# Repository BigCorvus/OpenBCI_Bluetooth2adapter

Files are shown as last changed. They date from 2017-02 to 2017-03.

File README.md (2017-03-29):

# OpenBCI_Bluetooth2adapter

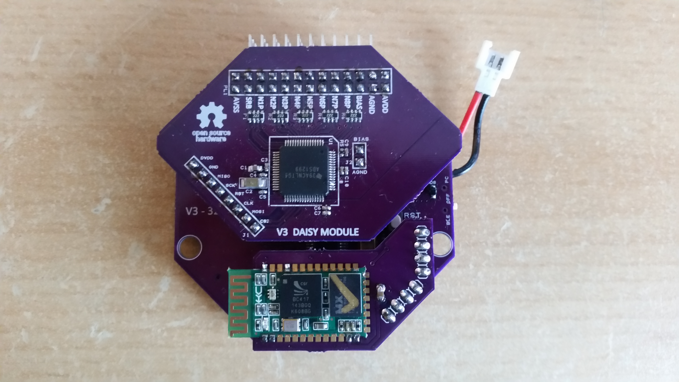
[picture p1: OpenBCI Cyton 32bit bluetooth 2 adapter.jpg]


Eagle files for an adapter board for the OpenBCI 32bit V3 board (Cyton) that enables higher data/sampling rates and eliminates the need for a USB dongle. Reliable operation is possible with 500Hz and 8 channels or 250Hz and 16 Channels. The OpenBCI GUI 2.0 is able to keep up with that.
The bluetooth module used is the common HC-05. Programming the board is still accomplished via dongle/RFduino.

In order for this board to work you have to implement WinslowStrong's changes in firmware (https://github.com/WinslowStrong/OpenBCI_Wired_USB) and you have to set up a baud rate of 230400baud on your bluetooth module (this is the highest rate I've been able to acheive reliably with the HC05). 
I've modified my Cyton board by putting the RFduino module on headers so that it can be removed after flashing the modified firmware. 

A solder jumper is included on the bottom side of the board to enter programming mode. You can short it temporarily using some metal object. In command mode (the LED is blinking slowly) you have to set a baud rate of 38400baud 8N1 and send after each command \r\n. If you enter AT the module should respond with OK.
To set the baud rate just enter AT+UART=230400,0,0 and to set the name type in AT+NAME=OpenBCI32 or whatever name you like. 

Edit: I also created a version for the RN42 module (http://www.digikey.com/product-detail/en/microchip-technology/RN42-I-RM630/RN42-I-RM630-ND/6009311) which can acheive speeds at up to 460800 baud in the system.

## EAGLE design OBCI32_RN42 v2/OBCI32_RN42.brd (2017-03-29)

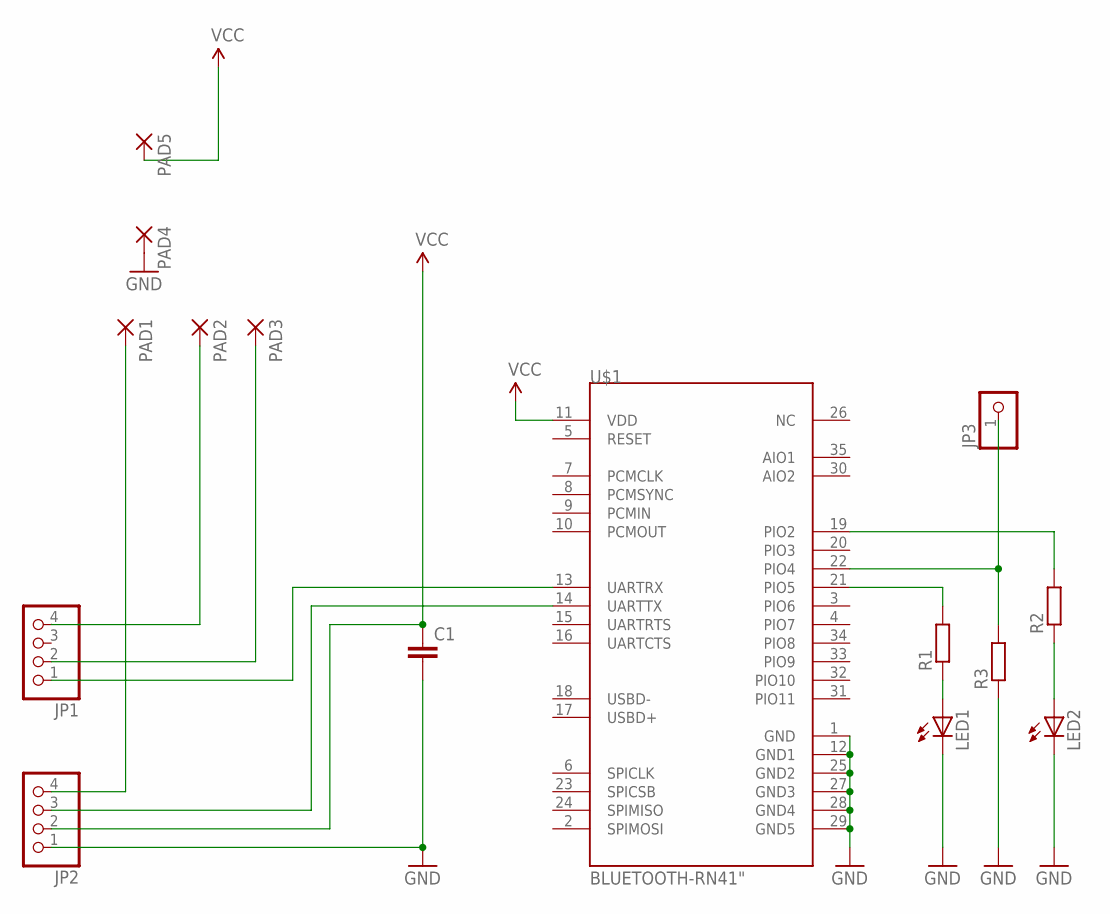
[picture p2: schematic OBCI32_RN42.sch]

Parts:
C1: C-EUC0805; C0805
JP1, JP2: PINHD-1X4; 1X04
JP3: PINHD-1X1; 1X01
LED1, LED2: LEDCHIP-LED0805; CHIP-LED0805
PAD1, PAD2, PAD3, PAD4, PAD5: SMD2; SMD1,27-2,54
R1, R2, R3: R-EU_R0603; R0603
U$1: BLUETOOTH-RN41"; RN41

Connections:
GND: C1.2, JP2.1, LED1.C, LED2.C, PAD4.1, R3.1, U$1.1 (GND), U$1.12 (GND1), U$1.25 (GND2), U$1.27 (GND3), U$1.28 (GND4), U$1.29 (GND5)
unnamed: R1.2, U$1.21 (PIO5)
unnamed: R2.2, U$1.19 (PIO2)
unnamed: JP2.3, U$1.14 (UARTTX)
unnamed: JP1.1, U$1.13 (UARTRX)
unnamed: LED1.A, R1.1
unnamed: JP1.2, PAD3.1
unnamed: JP1.4, PAD2.1
unnamed: JP2.4, PAD1.1
unnamed: LED2.A, R2.1
unnamed: JP3.1, R3.2, U$1.22 (PIO4)
VCC: C1.1, JP2.2, PAD5.1, U$1.11 (VDD)

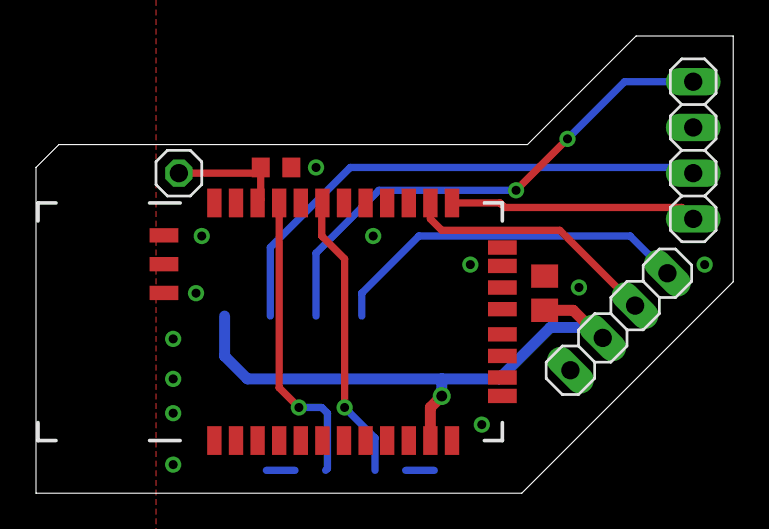
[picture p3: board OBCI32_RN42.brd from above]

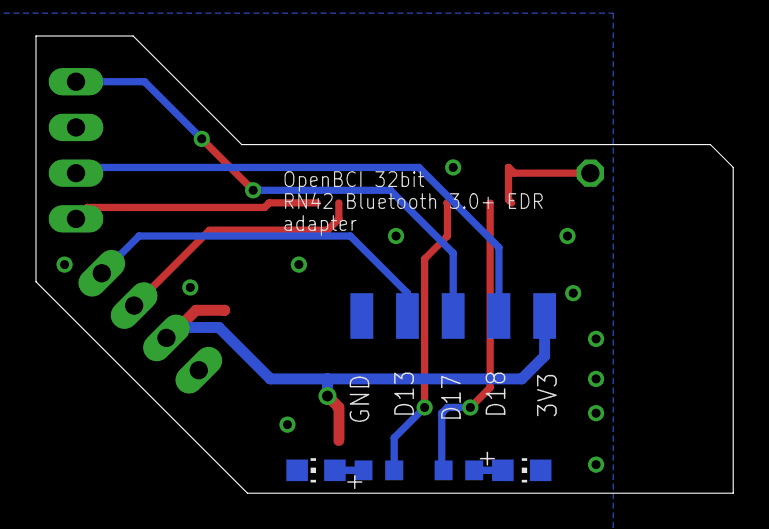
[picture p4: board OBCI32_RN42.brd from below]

Board: 2 copper layers, 38.7 x 25.4 mm, 15 parts (9 on the bottom side), 12 nets.

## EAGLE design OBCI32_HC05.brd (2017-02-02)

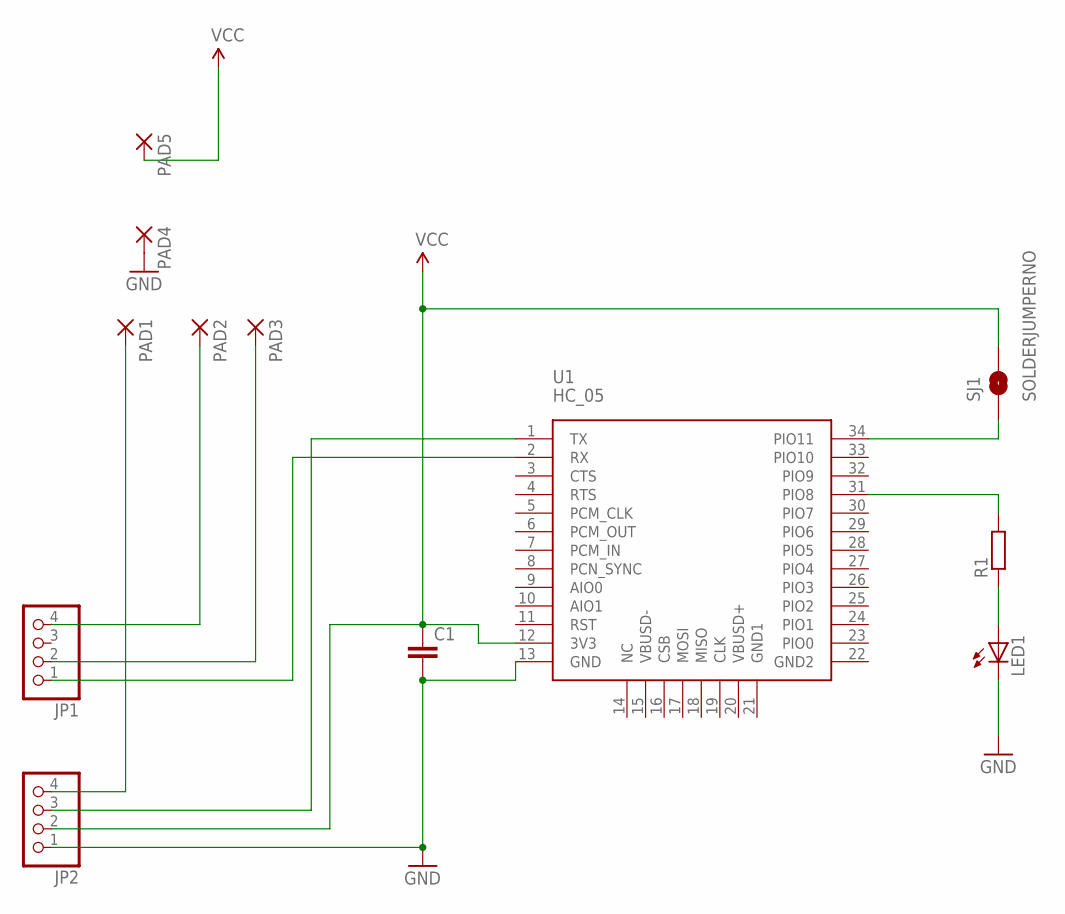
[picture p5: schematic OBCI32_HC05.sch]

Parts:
C1: C-EUC0805; C0805
JP1, JP2: PINHD-1X4; 1X04
LED1: LEDCHIP-LED0805; CHIP-LED0805
PAD1, PAD2, PAD3, PAD4, PAD5: SMD2; SMD1,27-2,54
R1: R-EU_R0603; R0603
SJ1: SOLDERJUMPERNO; SJ_2S-NO
U1: HC_05; BLUETOOTH_SMD

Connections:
GND: C1.2, JP2.1, LED1.C, PAD4.1, U1.13 (GND)
unnamed: LED1.A, R1.1
unnamed: JP2.3, U1.1 (TX)
unnamed: JP1.1, U1.2 (RX)
unnamed: R1.2, U1.31 (PIO8)
unnamed: SJ1.1, U1.34 (PIO11)
unnamed: JP1.2, PAD3.1
unnamed: JP1.4, PAD2.1
unnamed: JP2.4, PAD1.1
VCC: C1.1, JP2.2, PAD5.1, SJ1.2, U1.12 (3V3)

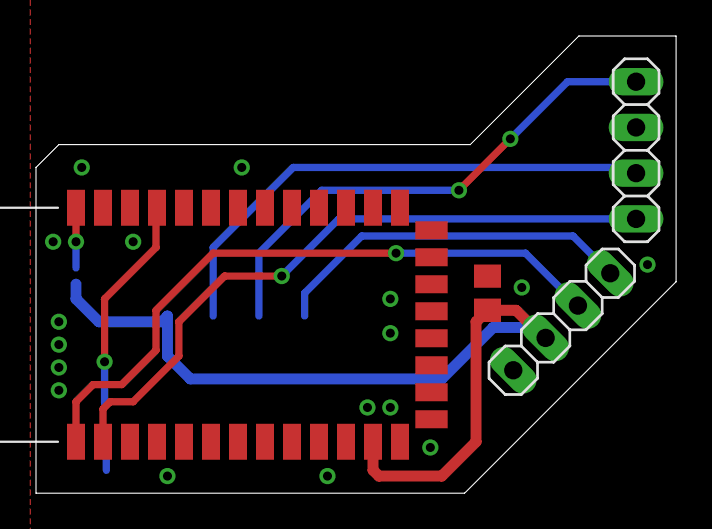
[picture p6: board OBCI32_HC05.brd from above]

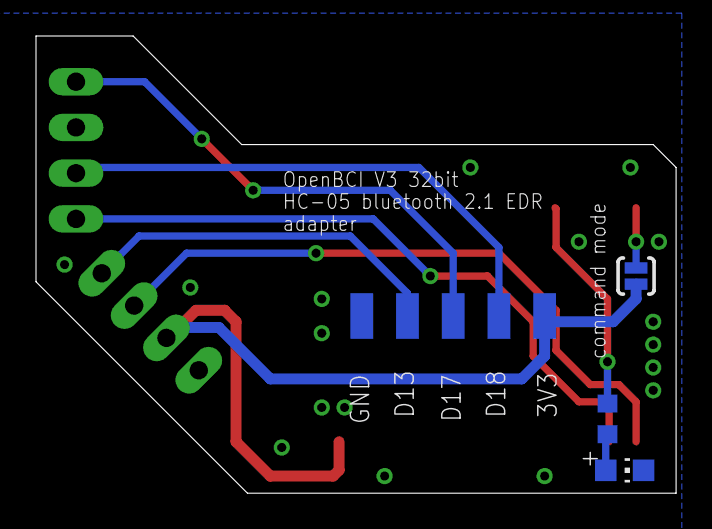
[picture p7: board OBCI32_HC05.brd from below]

Board: 2 copper layers, 35.6 x 25.4 mm, 12 parts (8 on the bottom side), 10 nets.

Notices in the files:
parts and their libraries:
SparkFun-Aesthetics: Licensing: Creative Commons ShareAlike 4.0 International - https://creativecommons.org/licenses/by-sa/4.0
